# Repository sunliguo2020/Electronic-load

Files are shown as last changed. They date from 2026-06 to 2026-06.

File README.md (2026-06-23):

# Electronic Load Project

这是一个基于 ESP32 的电子负载控制程序，适用于带有 160x80 TFT 显示屏、INA226 电量监测芯片、MCP4725 DAC 和旋转编码器的测试平台。

## 项目功能

- 实时显示电压、电流、功率、能量（Wh）、温度和运行时间
- 通过旋转编码器调整输出电流设定值
- 按下旋转编码器切换电子负载开/关
- 根据温度自动控制风扇
- 温度过高时自动关闭负载输出
- 使用 LVGL 在 TFT 显示屏上显示仪表信息

## 主要硬件组件

- ESP32 开发板
- TFT 显示屏（使用 `TFT_eSPI` 和 `LVGL` 驱动）
- INA226 电流/电压传感器
- MCP4725 I2C DAC
- 旋转编码器（带按键）
- 温度传感器（通过模拟输入读取并用 B3950 查表计算温度）
- 风扇控制接口
- 负载使能输出

## 代码说明

主要代码位于 `01 Software/ele_load/ele_load.ino`：

- `setup()`
  - 初始化串口、TFT、LVGL、I2C 设备
  - 初始化 INA226 并进入连续测量模式
  - 初始化旋转编码器输入

- `loop()`
  - 调用 `lv_task_handler()` 更新图形界面
  - 调用 `ina266_task()` 获取 INA226 电压、电流、功率，并更新显示
  - 调用 `time_update_task()` 更新运行时钟
  - 调用 `button_handle_task()` 处理旋转编码器输入，包括开/关和电流调节

- 温度读取和风扇控制
  - 通过 `analogRead(38)` 和 `analogRead(37)` 读取温度和电池相关 ADC 值
  - 使用 `B3950.h` 中的温度查表进行热敏电阻温度换算
  - 50°C 以上开启风扇，90°C 以上断开输出

## 引脚定义

- `OUT_EN_PIN`：25，负载输出使能
- `FAN_CTL_PIN`：14，风扇控制
- `LCD_BL`：26，LCD 背光（代码中定义但未显式使用）
- `PinA`：19，旋转编码器 A
- `PinB`：23，旋转编码器 B
- `PinC`：26，旋转编码器按键

## 依赖库

- `lvgl`
- `TFT_eSPI`
- `lv_examples`
- `Wire`
- `Bounce2`
- `INA.h`
- `SPI`
- `Ticker`
- `MD_REncoder`

## 使用方法

1. 在 Arduino IDE 或 PlatformIO 中打开 `01 Software/ele_load/ele_load.ino`。
2. 安装上述依赖库。
3. 根据实际硬件连接调整引脚定义和 I2C 地址。
4. 将程序上传到 ESP32。
5. 连接 INA226、电源负载和显示屏，并旋转编码器调整设定值。

## 备注

- 代码中 `stopvol_label` 用于显示截止电压，但当前实现中未关联实际截止阈值控制逻辑。
- `B3950.h` 包含基于 B3950 热敏电阻的温度查表，用于温度显示和保护。
- 代码默认 I2C DAC 地址为 `0x60`。

---

如需扩展功能，可考虑增加：
- 精确的截止电压保护
- 电流设定显示界面
- 更复杂的负载模式（恒流、恒压、恒功率）
- 持久化设置存储

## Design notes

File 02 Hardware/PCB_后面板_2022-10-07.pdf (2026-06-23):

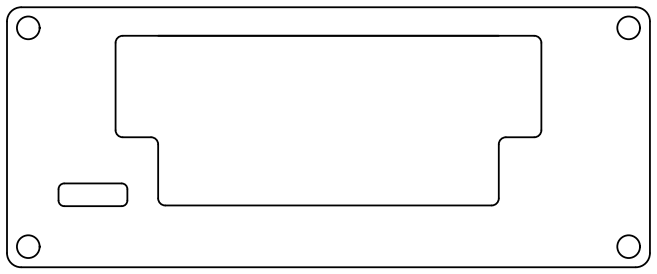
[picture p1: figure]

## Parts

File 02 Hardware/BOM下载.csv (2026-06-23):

ID | Name | Designator | Footprint | Quantity
1 | 10uF | C1,C53,C54,C39,C40,C49 | C0603 | 6
2 | 0.1u | C2,C3,C6,C34,C55,C56,C57,C59 | C0402 | 8
3 | 22uF | C12 | C0805 | 1
4 | 0.1u | C35 | C0805 | 1
5 | 100nF | C41,C47,C48,C50 | C0603 | 4
6 | 100pF | C42 | C0402 | 1
7 | 10uF | C44,C45 | C1206 | 2
8 | 0.1u | C46 | C0603 | 1
9 | 0.1uF | C51,C52 | C0402 | 2
10 | 10u | C58 | C0402 | 1
11 | DB2ERC-3.81-4P-BK | CN1 | CONN-TH_4P-P3.81_DB2ERC-3.81-4P-BK | 1
12 | SMF30A_C364281 | D1 | SOD-123FL_L2.6-W1.6-LS3.4-R-FD | 1
13 | DSK34 | D7 | SOD-123_L2.8-W1.8-LS3.9-FD | 1
14 | B5819W_C8598 | D8 | SOD-123_L2.7-W1.6-LS3.7-RD-1 | 1
15 | SMAJ30A | D9 | SMA_L4.4-W2.8-LS5.4-R-RD | 1
16 | DC-042C-W-2.0 | DC2 | DC-IN-TH_DC-042C-W-2.0 | 1
17 | 35V20A | F2 | F1206 | 1
18 | 2510S-4P | FAN1 | CONN-TH_4P-P2.54_A2510S-4P | 1
19 | 0.5K-A-10PB | FPC2 | CONN-SMD_0.5K-A-10PB | 1
20 | 2p_2.54插座 | J | DIP-2PIN-2.54-RECT-2.54X2.54-E | 1
21 | 10uH | L4 | L0805 | 1
22 | 4.7uH | L5 | IND-SMD_L7.0-W6.6_FXL0630 | 1
23 | 6.8uH | L6 | L1207 | 1
24 | MF52 | NTC1 | RES-TH_L2.5-W2.5-P1.70-D0.3 | 1
25 | S8050 | Q1,Q10 | SOT-23(SOT-23-3) | 2
26 | IRFP4668 | Q2,Q7 | 卧式TO-247封装 | 2
27 | 1K | R1,R2,R3,R5,R6,R8,R9,R11,R49,R55,R13,R45 | R0402 | 12
28 | 20K | R4,R7 | R0402 | 2
29 | 10k | R10,R24 | R0402 | 2
30 | 100k | R27,R38,R39 | R0402 | 3
31 | 3K | R32 | R0402 | 1
32 | 57K | R33 | R0402 | 1
33 | 9k | R36,R37 | R0402 | 2
34 | 4.7K | R40,R41 | R0402 | 2
35 | 10K | R42 | R0603 | 1
36 | 0R | R47 | R0603 | 1
37 | 10K | R50 | R0402 | 1
38 | 33K | R51 | R0402 | 1
39 | 1M | R52 | R0402 | 1
40 | 0.005 | U3,U18 | R2512 | 2
41 | GH1.25-7PLTPZ | U4 | CONN-SMD_GH1.25-7PLTPZ | 1
42 | MCP4725A0T-E/CH | U9 | SOT-23-6_L2.9-W1.6-P0.95-LS2.8-BR | 1
43 | SX1308 | U10 | SOT-23-6_L2.9-W1.6-P0.95-LS2.8-BR | 1
44 | ME3116A | U11 | ME3116A | 1
45 | RS8557XF | U13 | SOT-23-5_L3.0-W1.7-P0.95-LS2.8-BR | 1
46 | 0.002 | U15 | R2512 | 1
47 | INA226AIDGSR | U16 | INA226-MSOP-10_10P | 1
48 | CH224K | U17 | ESSOP10-EP | 1
49 | ANT_CrossAir_CA-C03 | U22 | ANT_CROSSAIR_CA-C03 | 1
50 | ESP32-PICO-D4 | U23 | QFN-48_L7.0-W7.0-P0.50-BL-EP5.1 | 1
51 | TYPEC-304S-ACP16 | USB1 | USB-C-SMD_TYPEC-304S-ACP16 | 1
52 | LM324DT | U1 | SOIC-14_L8.7-W3.9-P1.27-LS6.0-BL | 1

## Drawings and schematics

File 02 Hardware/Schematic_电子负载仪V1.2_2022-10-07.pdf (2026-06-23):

## RH/RL = VOUT/0.6 -1

## 下载口

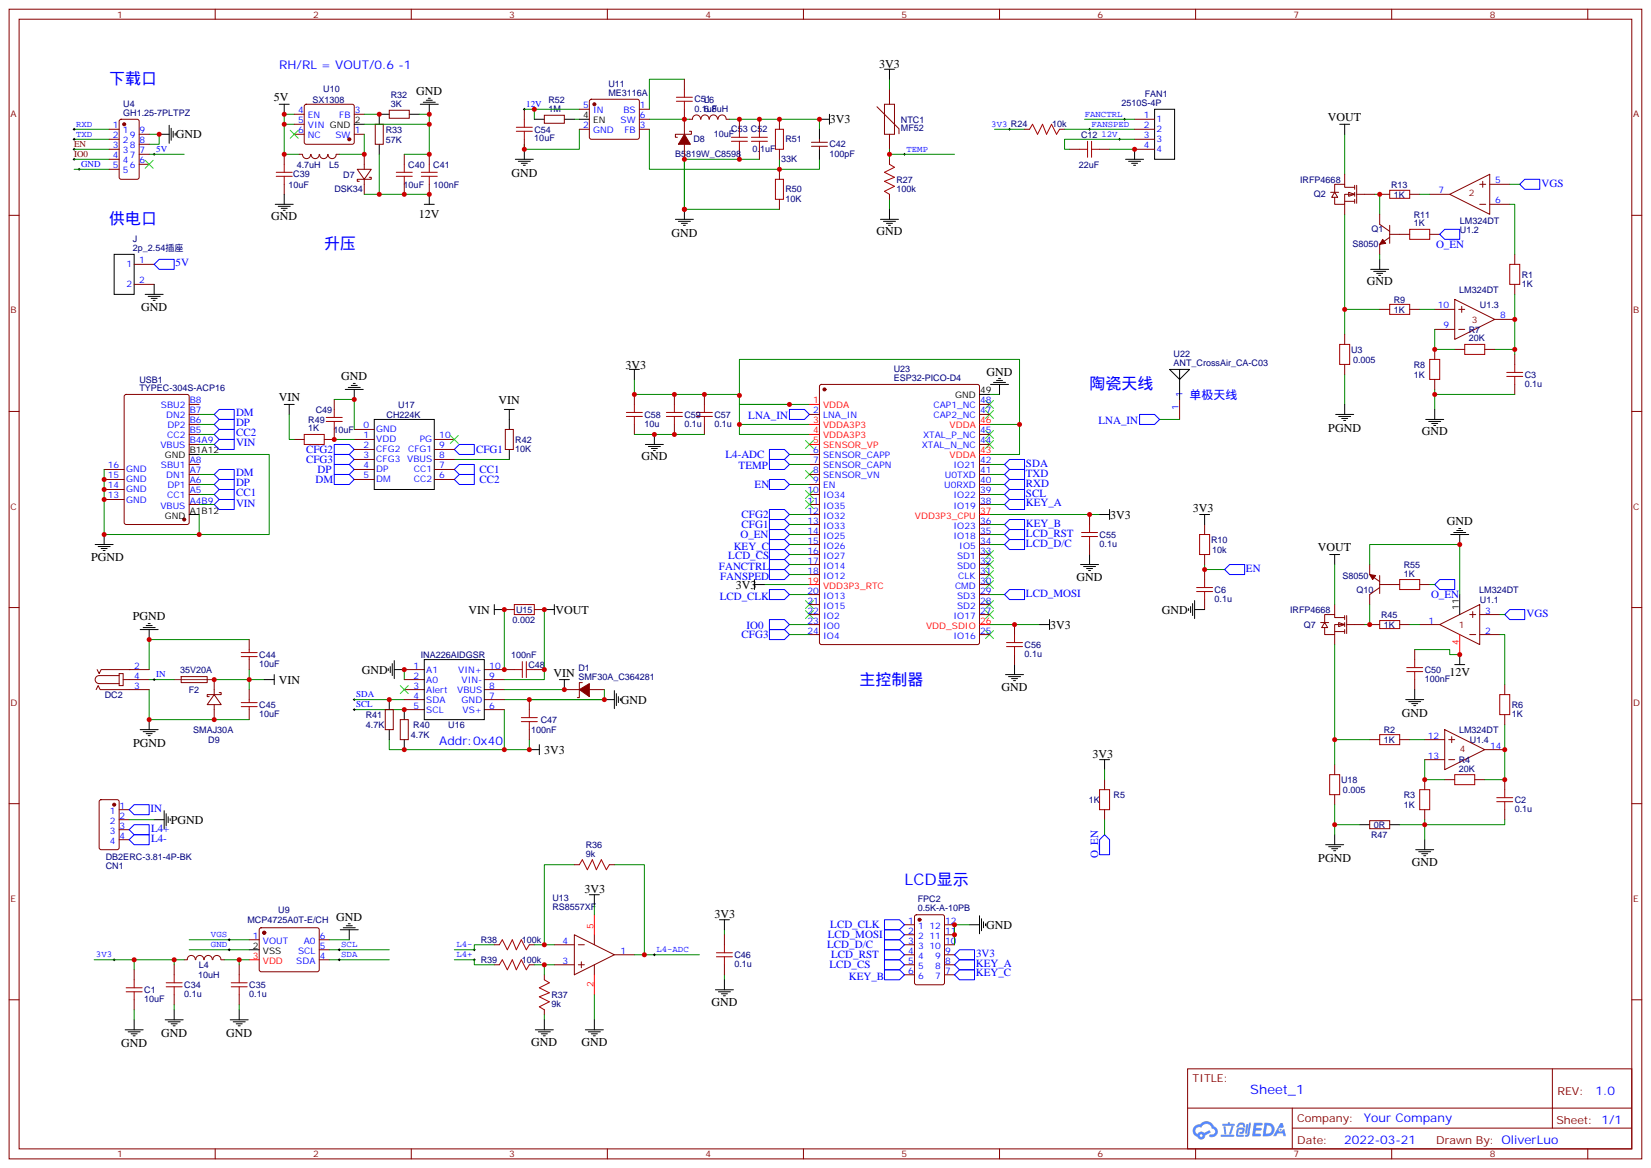
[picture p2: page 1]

GND 13 GND 14 GND 15 GND 16

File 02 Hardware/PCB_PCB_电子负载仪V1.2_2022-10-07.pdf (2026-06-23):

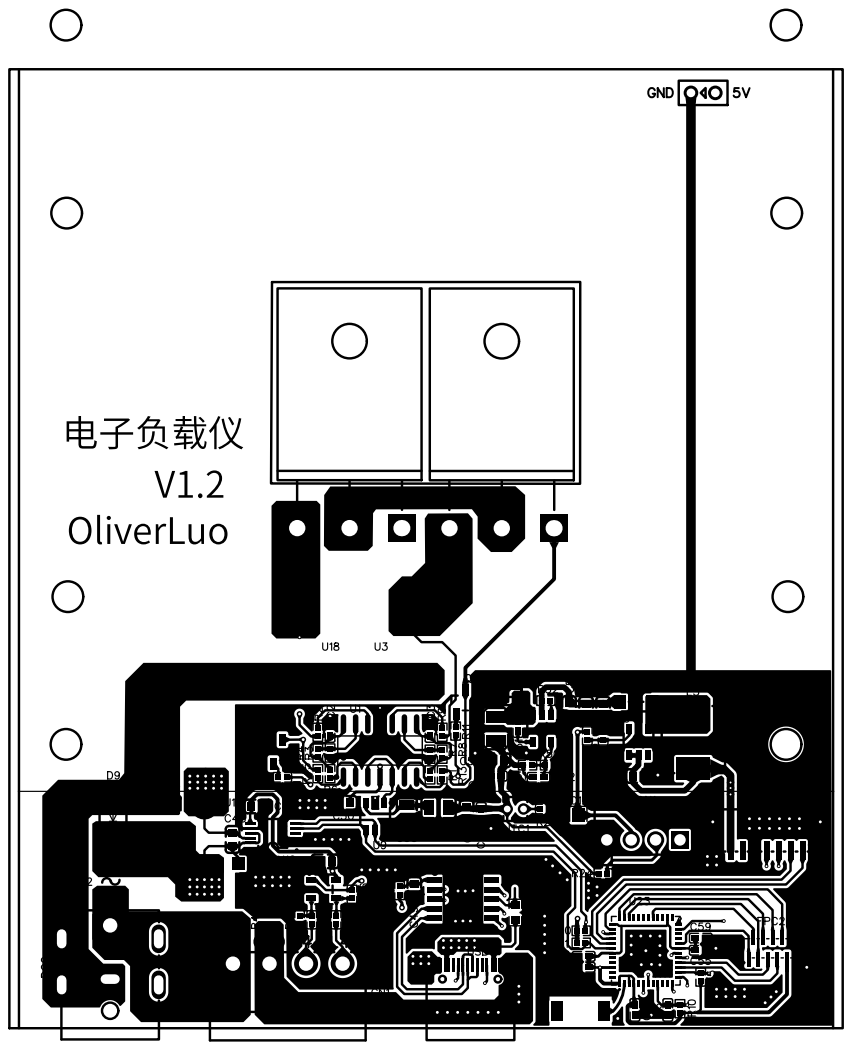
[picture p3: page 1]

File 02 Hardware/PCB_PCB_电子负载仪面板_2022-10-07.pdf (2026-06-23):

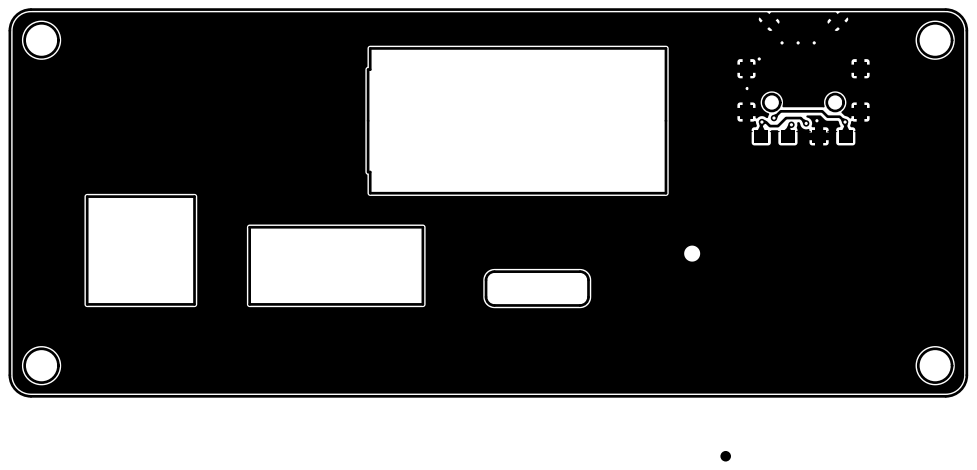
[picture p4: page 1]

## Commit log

2026-06-23 增加readme文件
2026-06-23 硬件部分
    [BOM下载.csv, Sheet_V1.2_2022-10-07.schdoc]
